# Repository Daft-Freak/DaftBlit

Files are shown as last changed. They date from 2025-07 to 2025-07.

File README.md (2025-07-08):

# DaftBlit
It's... a handheld console?

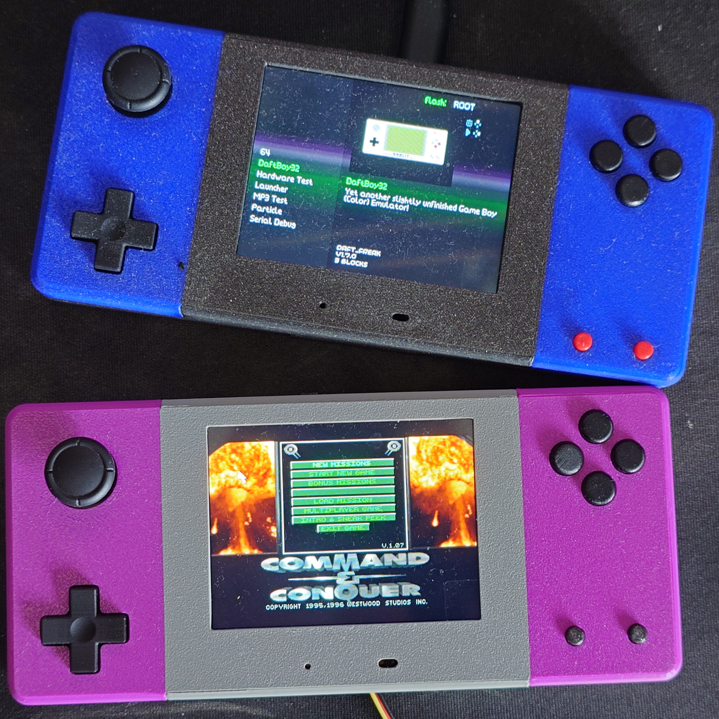
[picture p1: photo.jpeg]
photo of console


## Boards
- [Gamepads](https://github.com/Daft-Freak/py32-i2c-gamepad) (x2)
- `board/extra-buttons`: "Start/Select" buttons
- `board/display`: "Display" / main baard (has some sound/backlight issues)

## 3D Printed Parts
- `abxy.stl` A/B/X/Y buttons (x4)
- `console28-back.stl` back half of case
- `console28-front.stl` front half of case, should be printed face down
- `console28-dbg-cover` cover for debug port access
- `controller-mod-back.stl`/`controller-mod-front.stl` modifiers for multi-colour printing
- `dpad.stl` dpad, requires supports and a bit tricky to print
- `on-off-flat.stl` power button
- `start-select.stl` start/select buttons, requires supports and is very small (x2)

## Other hardware
- Button pads: 2x the dpad part from a GBA SP set.
- LCD: https://www.aliexpress.com/item/1005009128815676.html (2.8 inch 40 pin 240x320 ST7789)
- Speaker: TODO (can't remember if it's https://shop.pimoroni.com/products/mini-speaker-8-1w or not)
- Battery: TODO
- Screws: [TODO](assembly/00-screws2.jpeg) (there are four different ones)
- Cables: 1-2 "short" (50mm?) i2c cables and a longer one (100mm?), 5-pin 0.5mm ffc for start/select buttons
- Joystick: the switch joy-con one
- Brains: RP2350 stamp, the XL one if you want the power button to work
- Optional sensor stick for... sensors

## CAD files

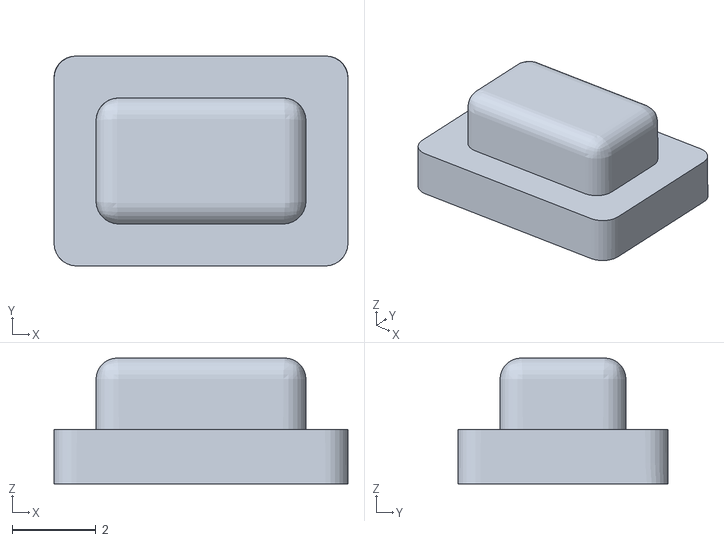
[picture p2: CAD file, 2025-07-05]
3d-print/on-off-flat.stl
7.00 x 5.00 x 3.00

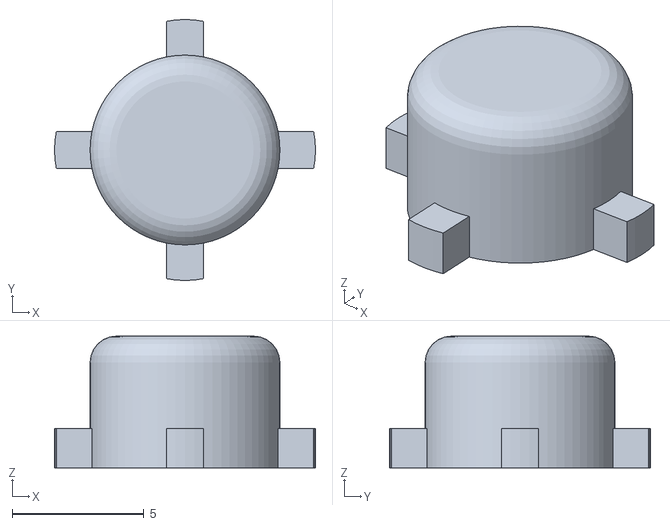
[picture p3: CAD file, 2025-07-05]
3d-print/abxy.stl
9.90 x 9.90 x 5.00

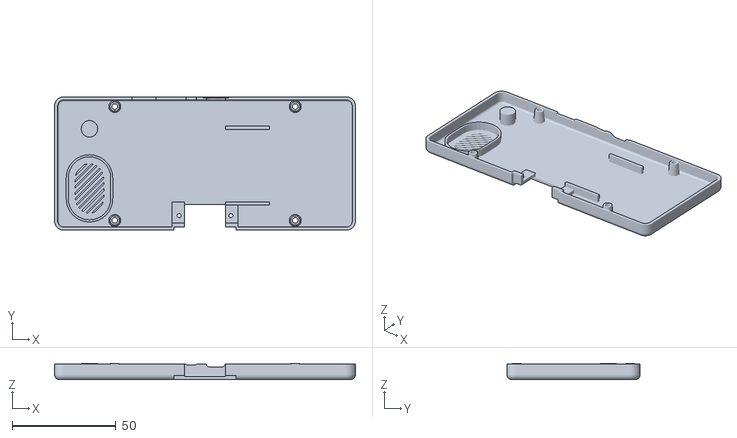
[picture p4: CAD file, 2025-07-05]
3d-print/console28-back.stl
145.4 x 64.4 x 7.85

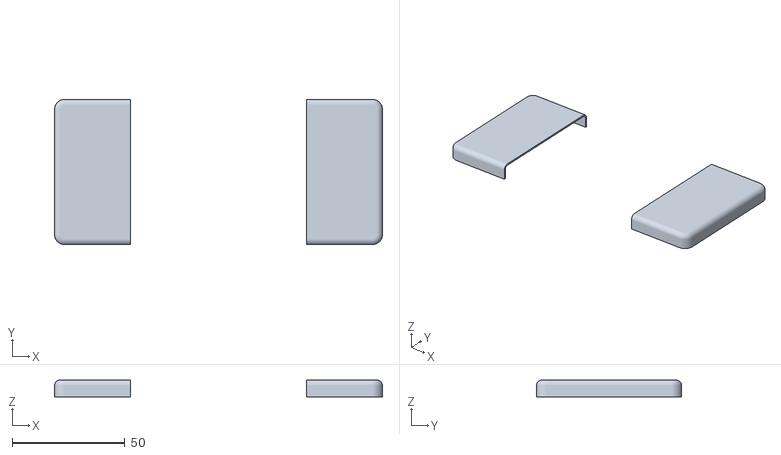
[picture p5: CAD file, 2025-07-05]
3d-print/controller-mod-front.stl
145.4 x 64.4 x 7.50

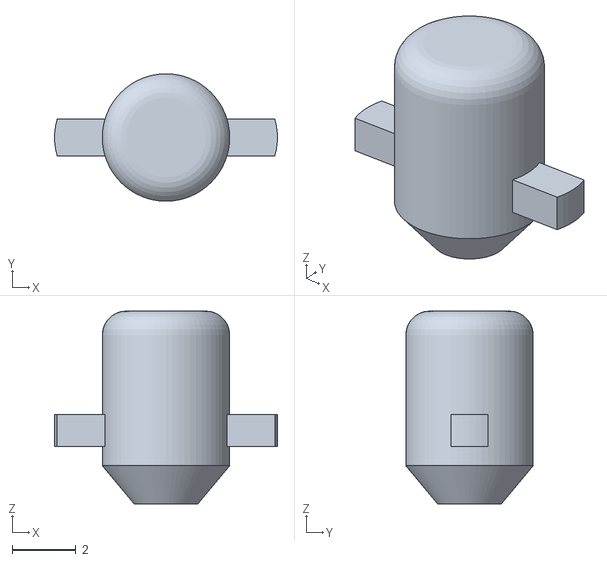
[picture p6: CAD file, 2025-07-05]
3d-print/start-select.stl
7.00 x 4.00 x 6.06

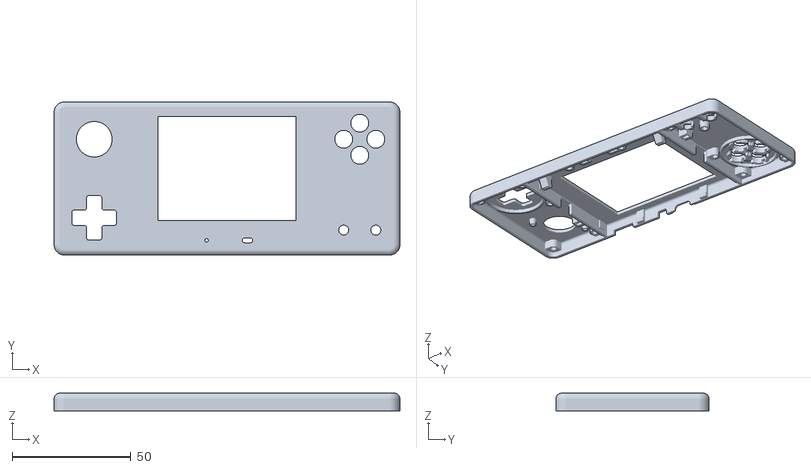
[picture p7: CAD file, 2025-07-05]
3d-print/console28-front.stl
145.4 x 64.4 x 7.50

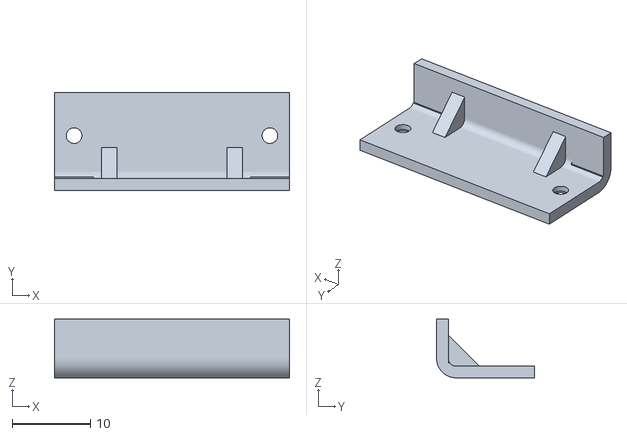
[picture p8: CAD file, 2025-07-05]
3d-print/console28-dbg-cover.stl
30.0 x 12.5 x 7.50

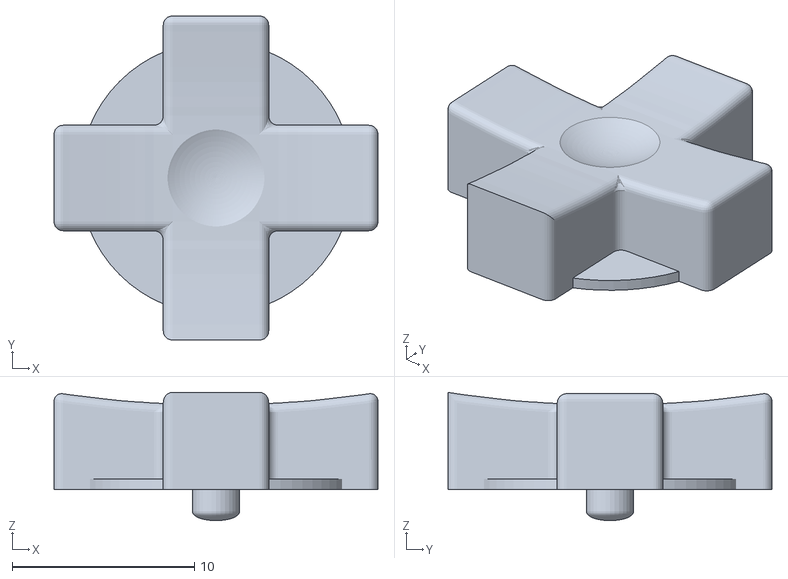
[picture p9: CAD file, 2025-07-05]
3d-print/dpad.stl
17.8 x 17.8 x 7.05

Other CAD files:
3d-print/controller-mod-back.stl

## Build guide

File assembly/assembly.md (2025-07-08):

## Parts
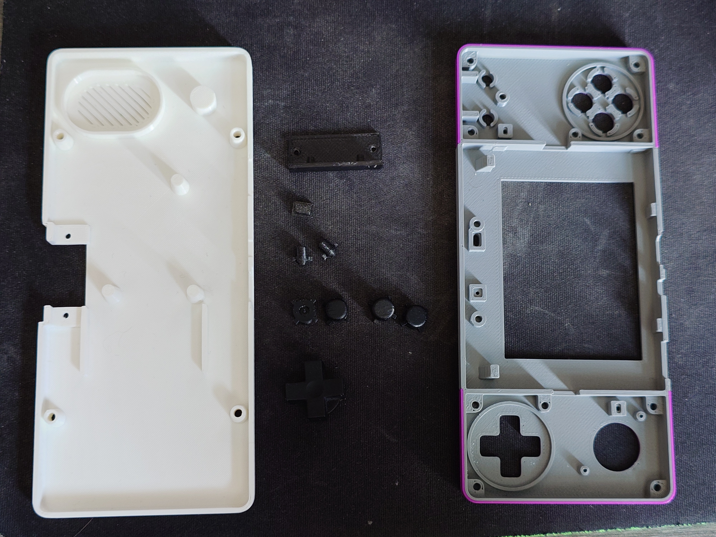
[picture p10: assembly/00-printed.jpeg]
Printed parts

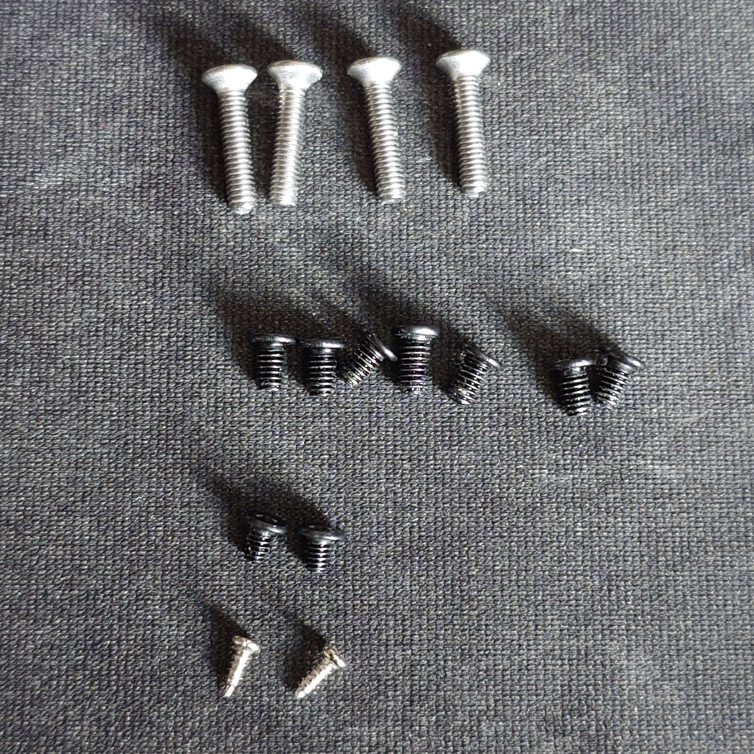
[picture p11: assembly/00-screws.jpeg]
Screws


- 4x M2.5 countersunk
- 5x M2.5 (+2 for sensor stick)
- 2x M2
- 2x ?? for joystick

(TODO: need to measure)

## 1 - Left controller

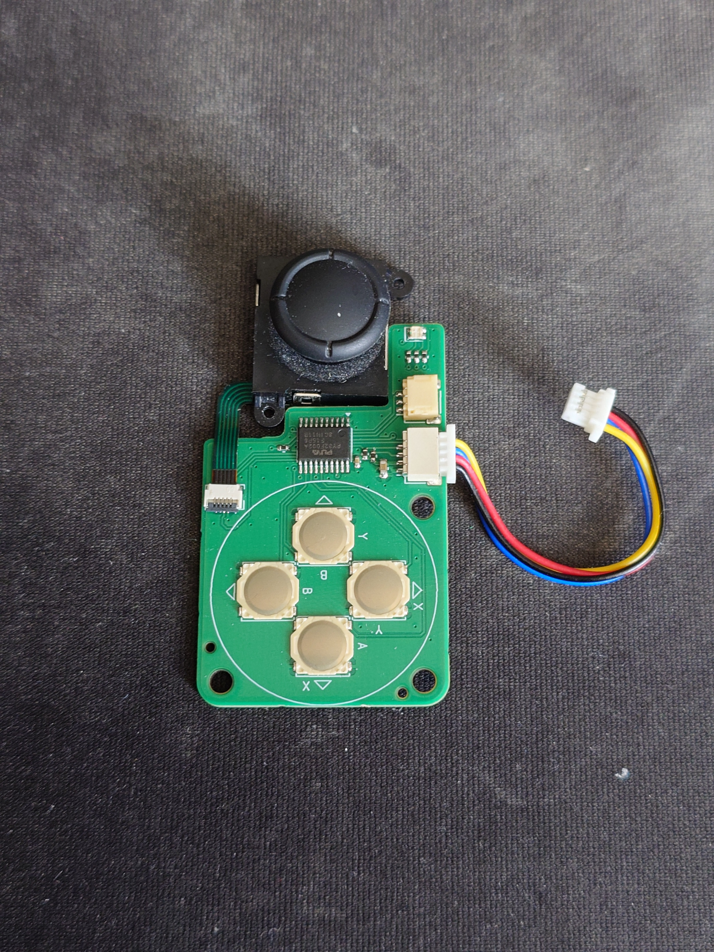
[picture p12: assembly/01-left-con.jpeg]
Left con


## 2 - Right controller

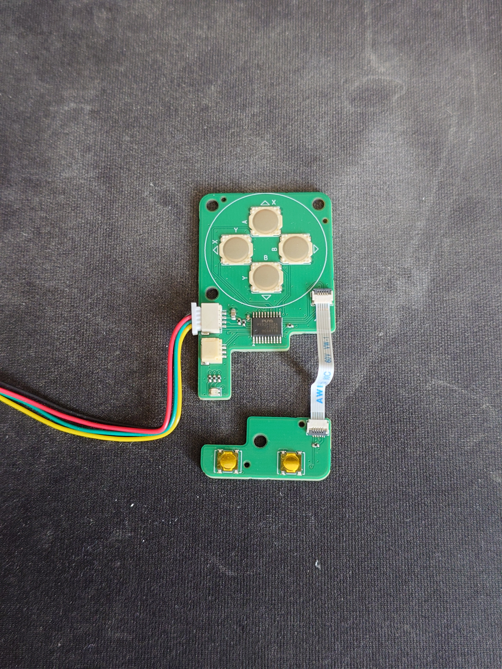
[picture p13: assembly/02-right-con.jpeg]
Right con


## 3 - Display/main board

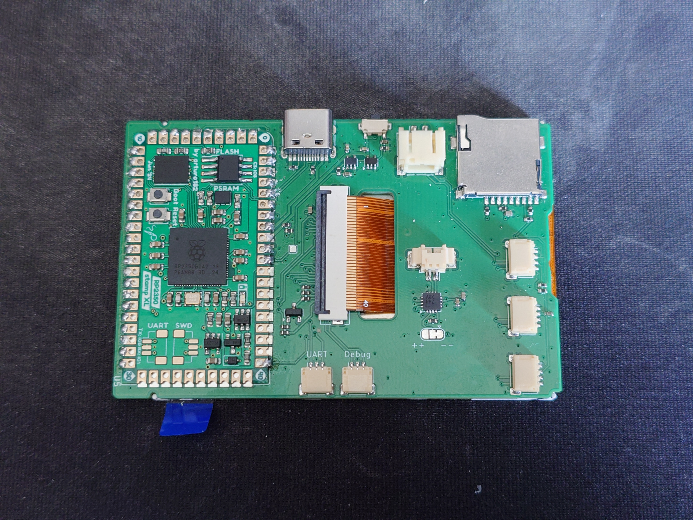
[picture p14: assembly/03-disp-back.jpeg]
Disp back

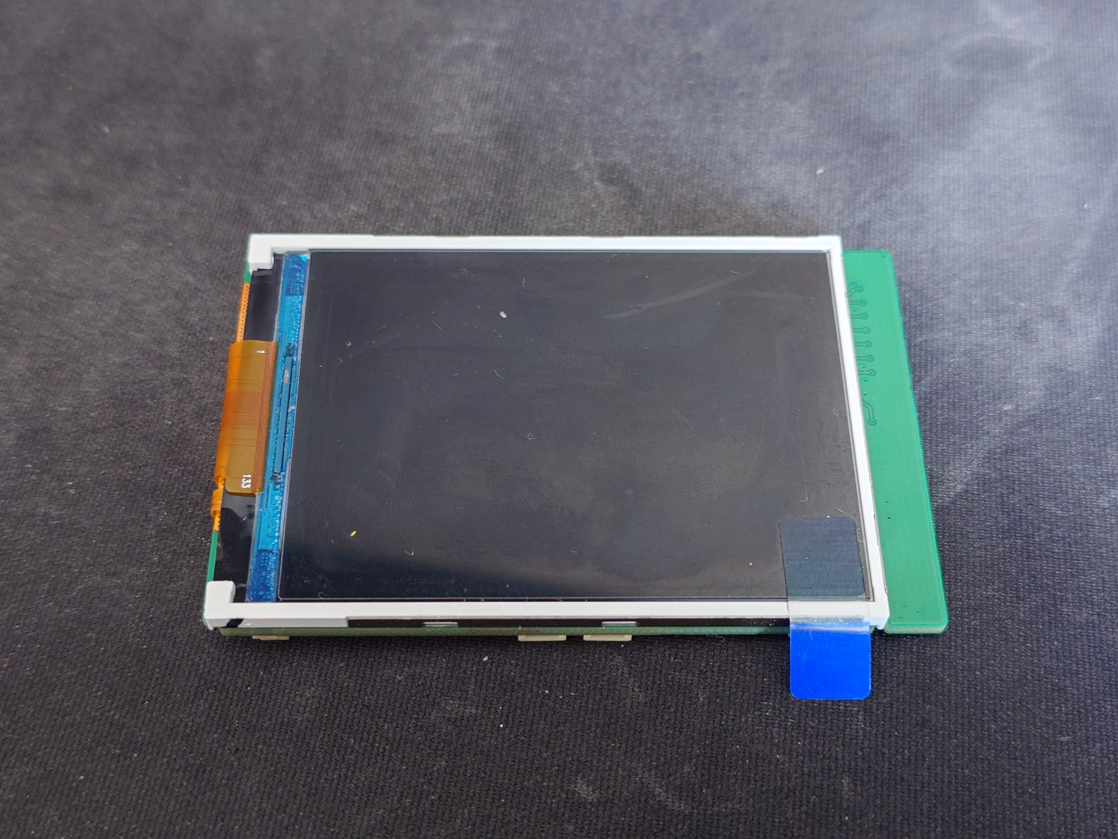
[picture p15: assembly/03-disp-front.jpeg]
Disp front


Stamp soldered, LCD connected and stuck down.

## 4 - Left controls

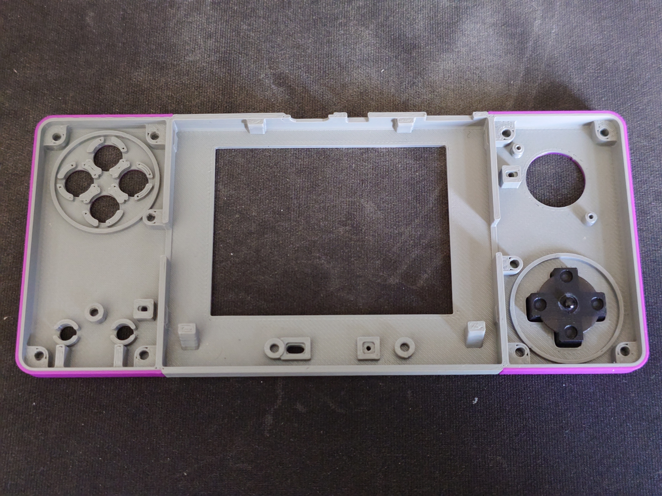
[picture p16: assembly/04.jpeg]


## 5 - 

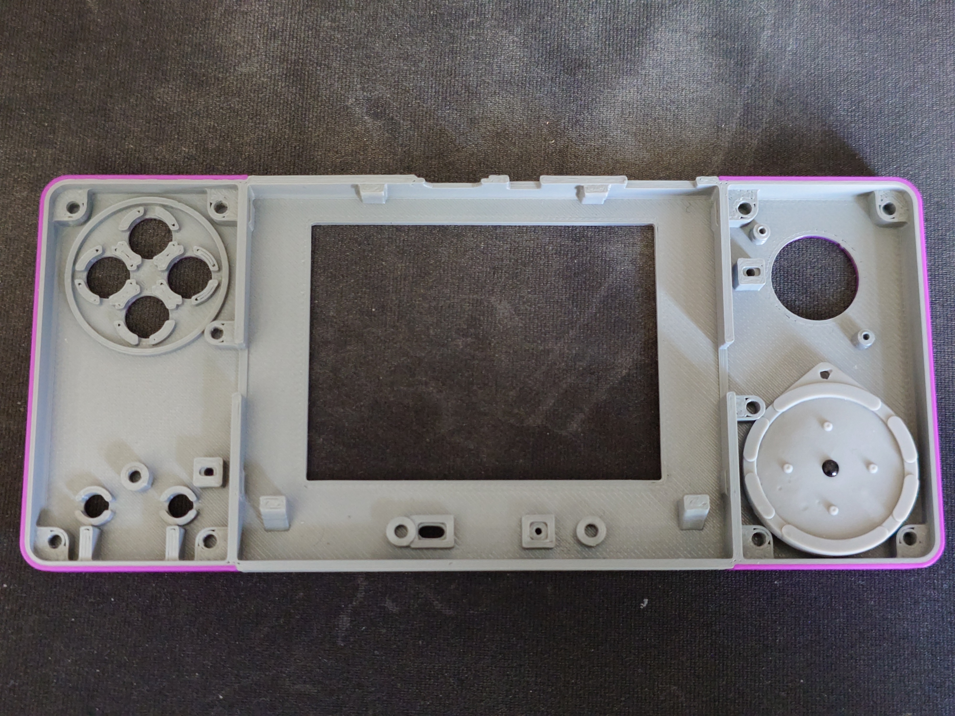
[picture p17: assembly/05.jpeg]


## 6 - 

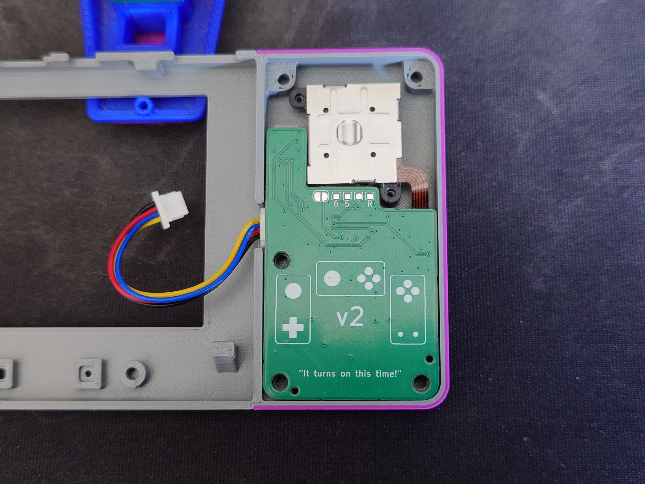
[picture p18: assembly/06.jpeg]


## 7 - 

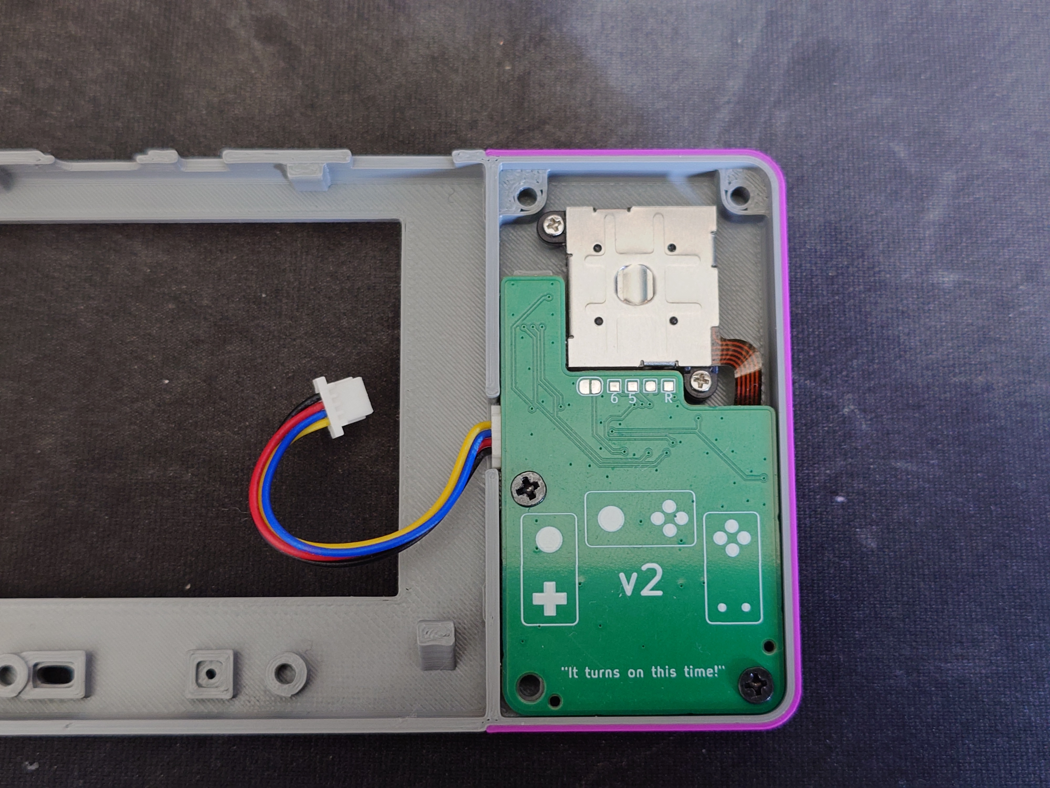
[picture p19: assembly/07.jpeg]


## 8 - Right controls

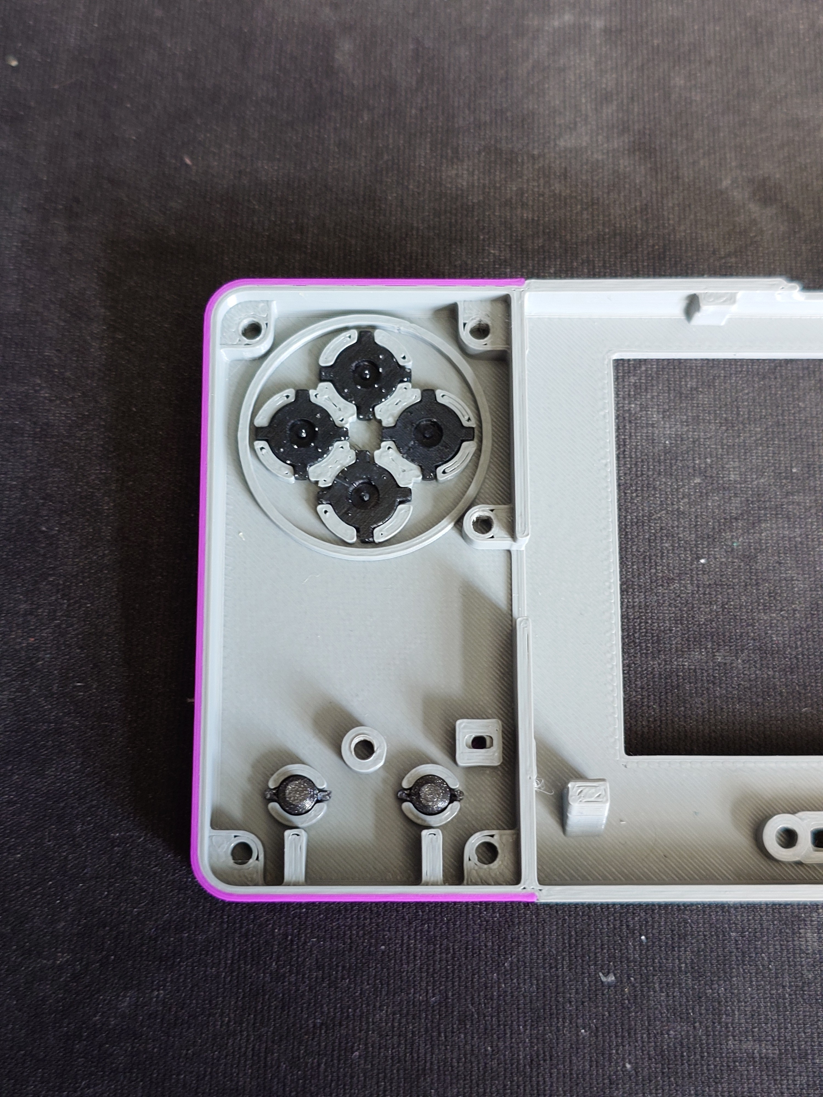
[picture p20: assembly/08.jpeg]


## 9 - 

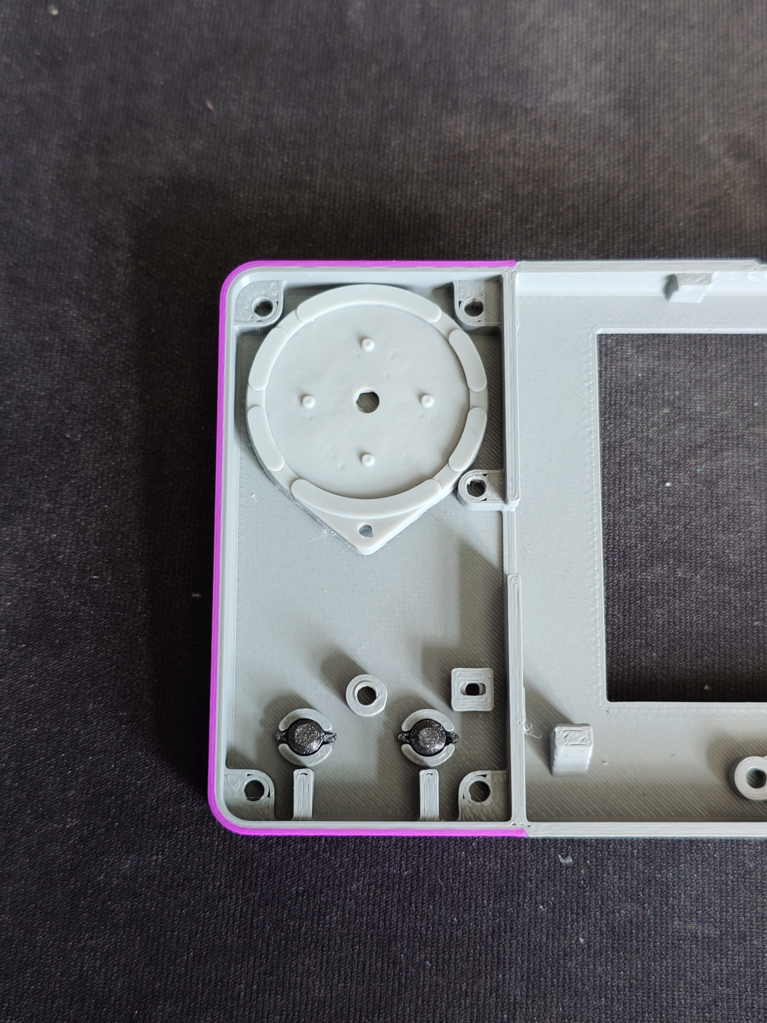
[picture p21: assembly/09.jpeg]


## 10 - 

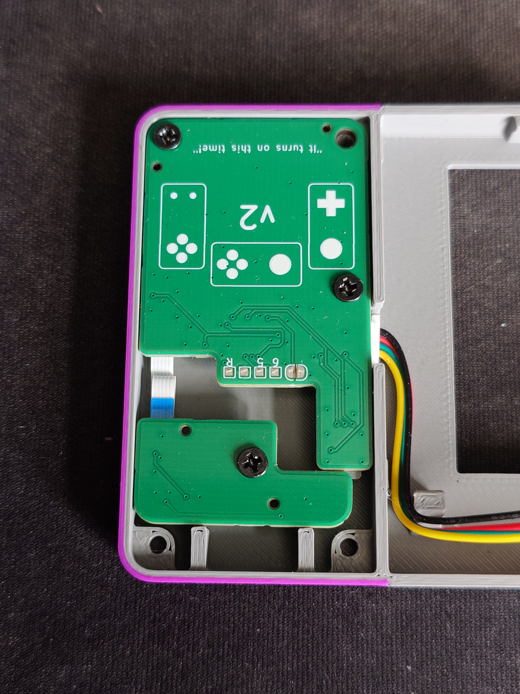
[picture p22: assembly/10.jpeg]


## 11 - Controls done

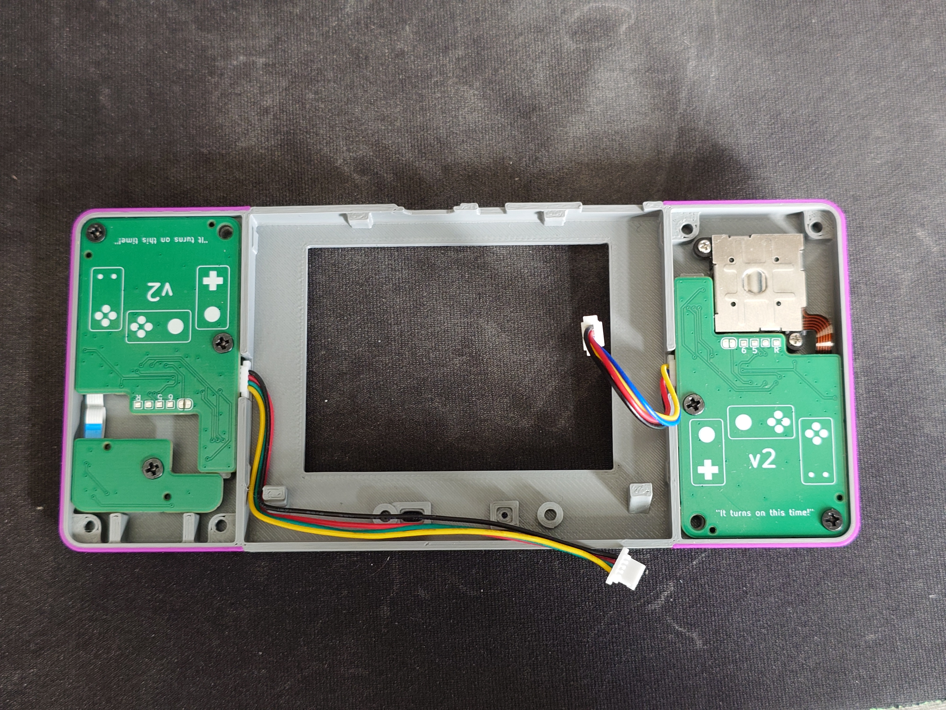
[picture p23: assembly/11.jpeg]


## 12 - Main board

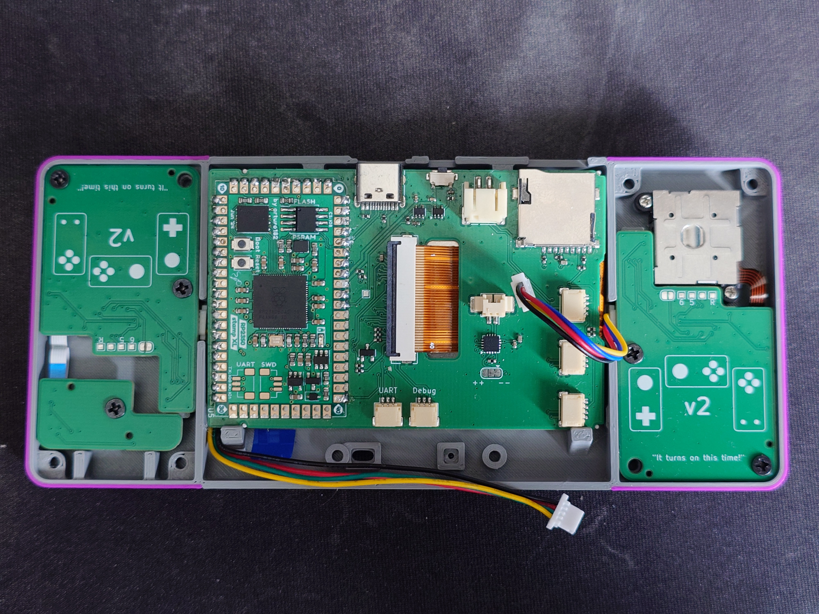
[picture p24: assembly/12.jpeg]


## 13 - 

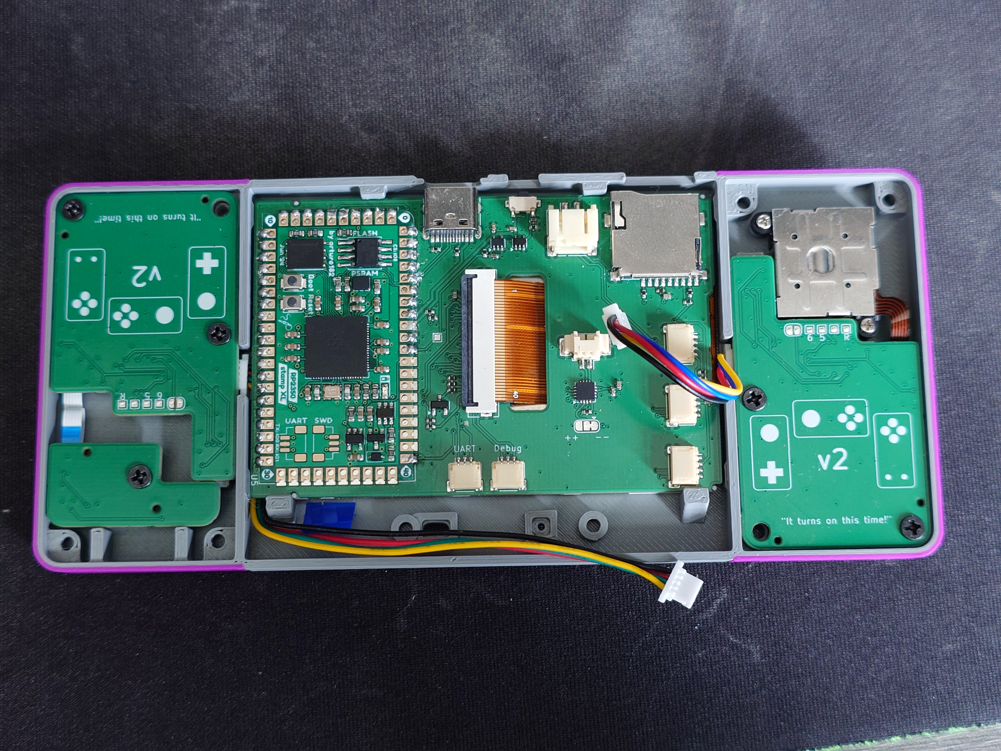
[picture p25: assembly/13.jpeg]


## 14 - 

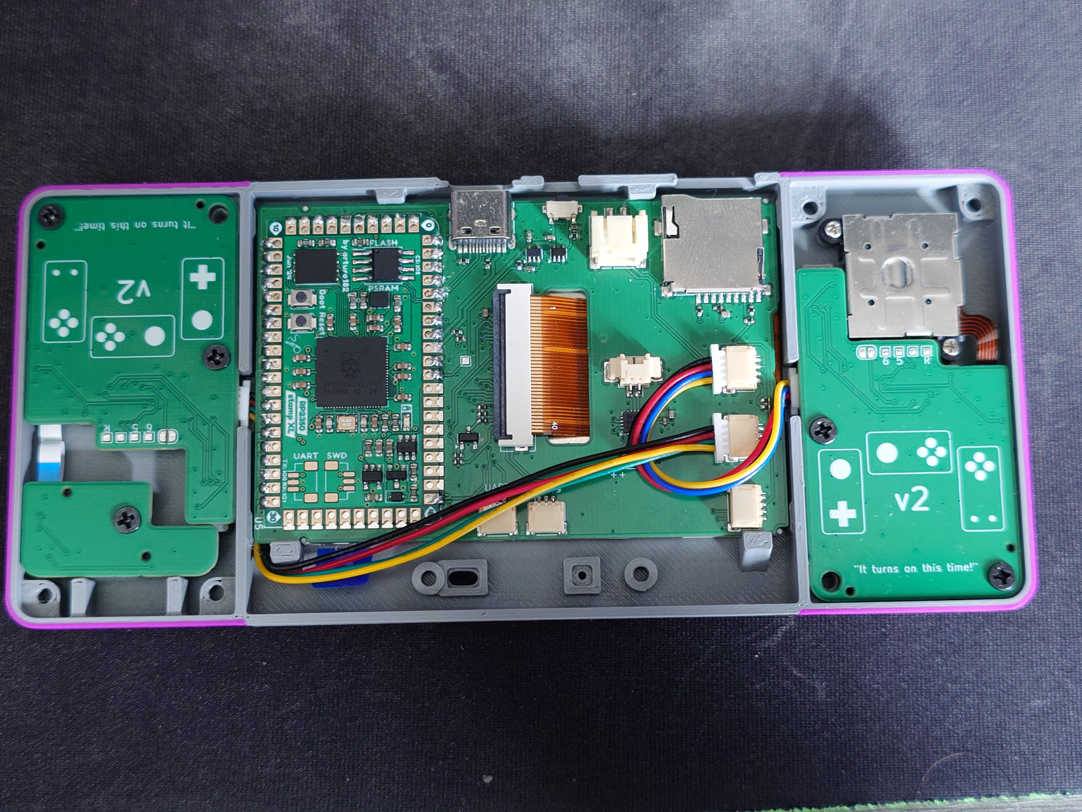
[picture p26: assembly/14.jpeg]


## 15 - Sensor stick (optional)

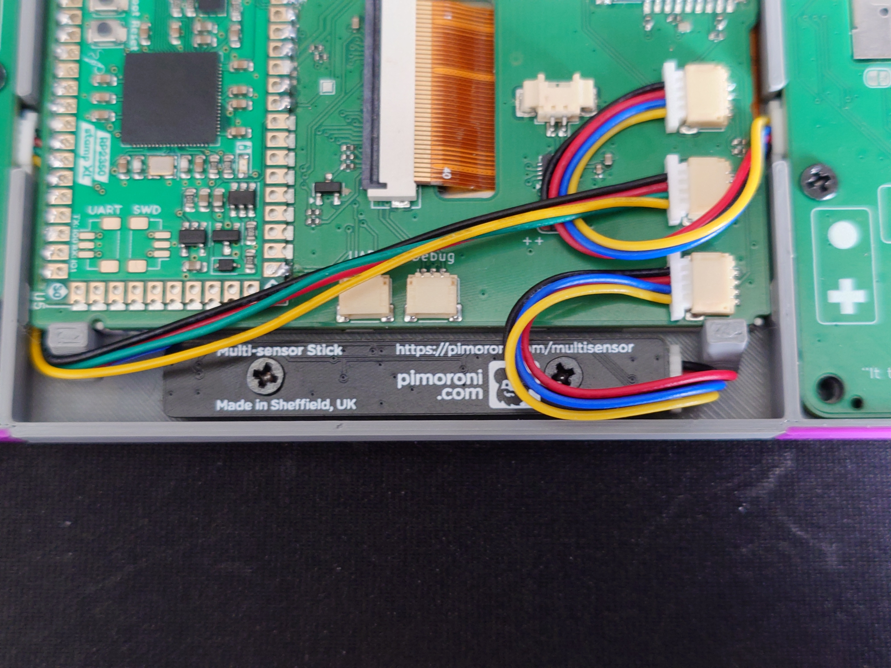
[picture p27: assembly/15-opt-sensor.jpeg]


## ...

- speaker
- battery
- closing case
- debug cover

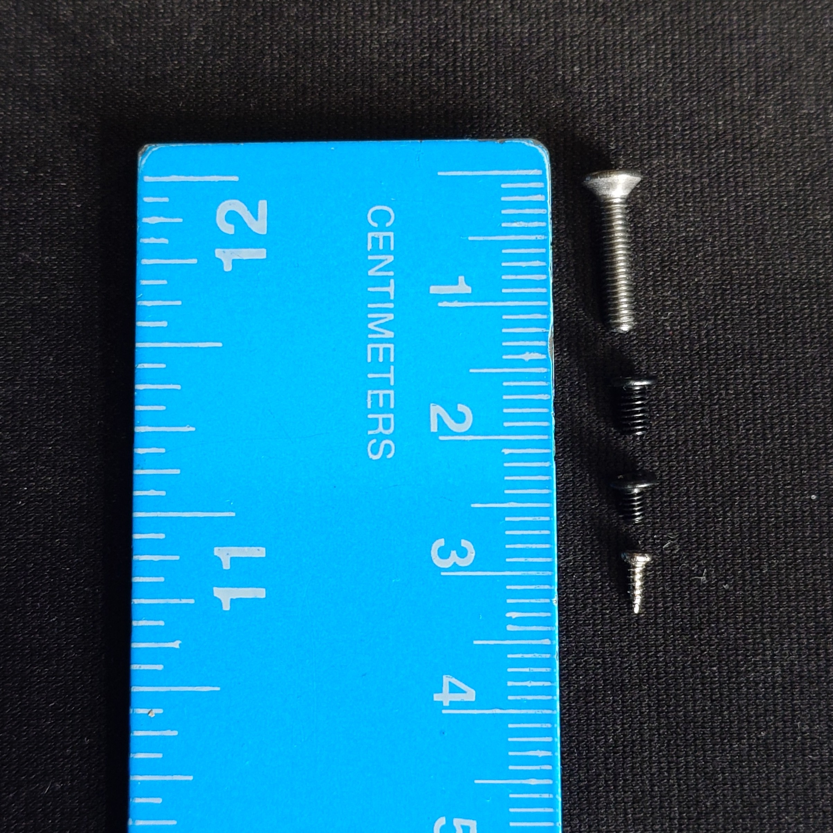
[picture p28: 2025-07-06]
assembly/00-screws2.jpeg

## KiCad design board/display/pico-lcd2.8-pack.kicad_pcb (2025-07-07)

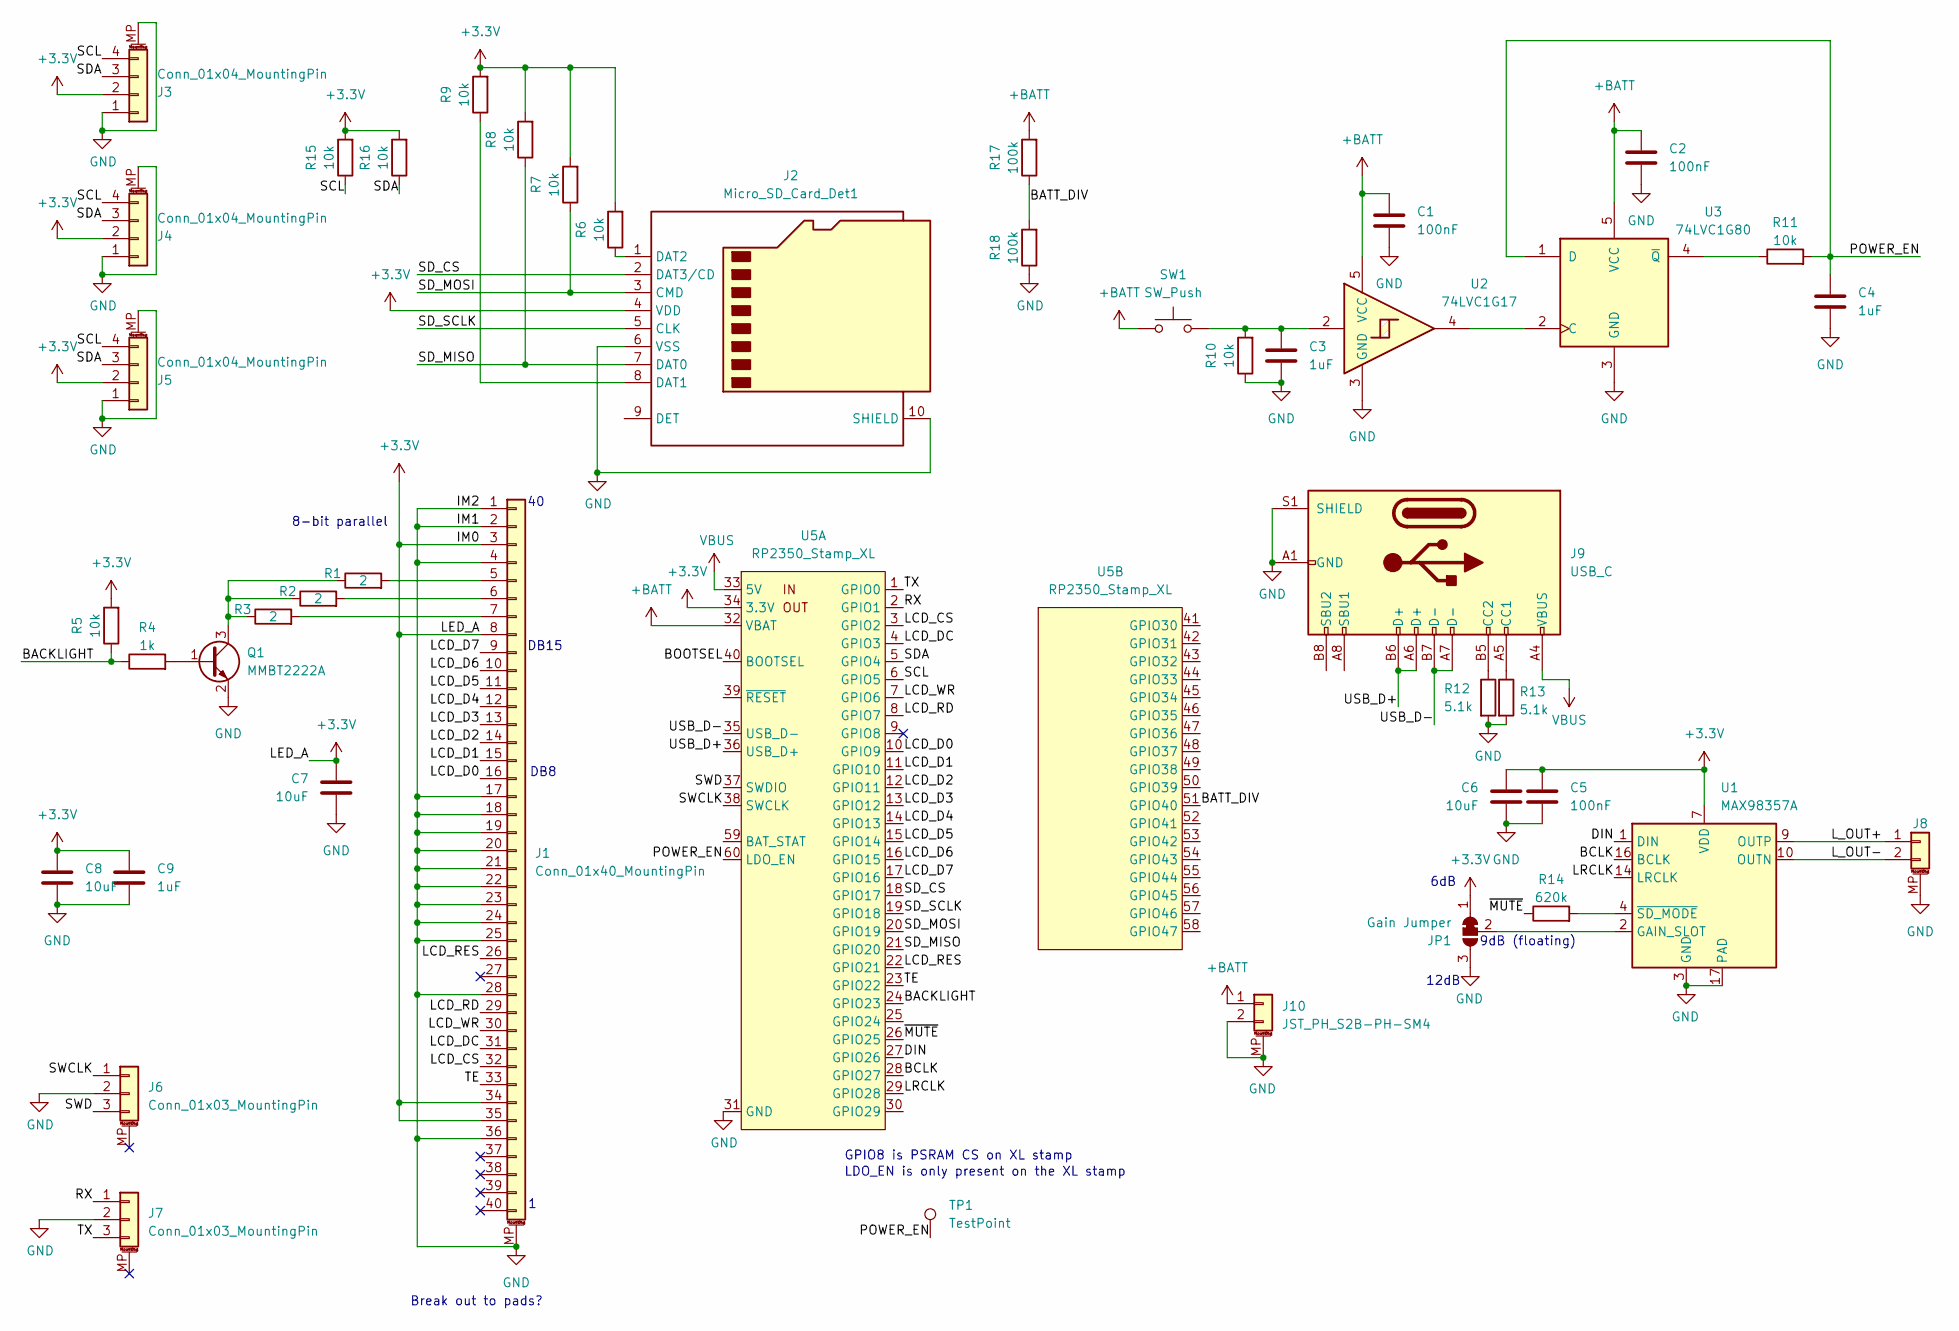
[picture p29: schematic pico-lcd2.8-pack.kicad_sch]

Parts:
C1, C2, C5: 100nF; C_0402_1005Metric
C3, C4, C9: 1uF; C_0402_1005Metric
C6, C7, C8: 10uF; C_0402_1005Metric
J1: Conn_01x40_MountingPin; XUNPU_FPC-05FB-40PH20_1x40-1MP_P0.50mm_Horizontal
J2: Micro_SD_Card_Det1; microSD_HC_Push
J3, J4, J5: Conn_01x04_MountingPin; JST_SH_SM04B-SRSS-TB_1x04-1MP_P1.00mm_Horizontal
J6, J7: Conn_01x03_MountingPin; JST_SH_SM03B-SRSS-TB_1x03-1MP_P1.00mm_Horizontal
J8: 1X02PICOBLADE; Molex_PicoBlade_53261-0271_1x02-1MP_P1.25mm_Horizontal
J9: USB_C; USB_C_Receptacle_HRO_TYPE-C-31-M-12
J10: JST_PH_S2B-PH-SM4; JST_PH_S2B-PH-SM4-TB_1x02-1MP_P2.00mm_Horizontal
JP1: Gain Jumper; SolderJumper-3_P1.3mm_Bridged12_RoundedPad1.0x1.5mm
Q1: MMBT2222A; SOT-23
R1, R2, R3: 2; R_0402_1005Metric
R4: 1k; R_0402_1005Metric
R5, R6, R7, R8, R9, R10, R11, R15, R16: 10k; R_0402_1005Metric
R12, R13: 5.1k; R_0402_1005Metric
R14: 620k; R_0402_1005Metric
R17, R18: 100k; R_0402_1005Metric
SW1: SW_Push; SW_Push_TSA002
TP1: TestPoint; TestPoint_Pad_1.0x1.0mm
U1: MAX98357A; TQFN-16-1EP_3x3mm_P0.5mm_EP1.23x1.23mm
U2: 74LVC1G17; SOT-353_SC-70-5
U3: 74LVC1G80; SOT-353_SC-70-5
U5: RP2350_Stamp_XL; RP2xxx_Stamp_Combo_SMD

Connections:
+3.3V: C5.1, C6.1, C7.1, C8.1, C9.1, J1.3, J1.8, J1.34, J1.35, J2.4 (VDD), J3.2, J4.2, J5.2, JP1.1 (A), R5.2, R6.2, R7.2, R8.2, R9.2, R15.2, R16.2, U1.7 (VDD), U1.8 (VDD), U5.34 (3.3V)
+BATT: C1.1, C2.1, J10.1, R17.2, SW1.1, U2.5 (VCC), U3.5 (VCC), U5.32 (VBAT)
/BACKLIGHT: R4.1, R5.1, U5.24 (GPIO23)
/BATT_DIV: R17.1, R18.2, U5.51 (GPIO40)
/BCLK: U1.16 (BCLK), U5.28 (GPIO27)
/BOOTSEL: U5.40 (BOOTSEL)
/DIN: U1.1 (DIN), U5.27 (GPIO26)
/LCD_CS: J1.32, U5.3 (GPIO2)
/LCD_D0: J1.16, U5.10 (GPIO9)
/LCD_D1: J1.15, U5.11 (GPIO10)
/LCD_D2: J1.14, U5.12 (GPIO11)
/LCD_D3: J1.13, U5.13 (GPIO12)
/LCD_D4: J1.12, U5.14 (GPIO13)
/LCD_D5: J1.11, U5.15 (GPIO14)
/LCD_D6: J1.10, U5.16 (GPIO15)
/LCD_D7: J1.9, U5.17 (GPIO16)
/LCD_DC: J1.31, U5.4 (GPIO3)
/LCD_RD: J1.29, U5.8 (GPIO7)
/LCD_RES: J1.26, U5.22 (GPIO21)
/LCD_WR: J1.30, U5.7 (GPIO6)
/LRCLK: U1.14 (LRCLK), U5.29 (GPIO28)
/L_OUT+: J8.1, U1.9 (OUTP)
/L_OUT-: J8.2, U1.10 (OUTN)
/POWER_EN: C4.1, R11.2, TP1.1, U3.1 (D), U5.60 (LDO_EN)
/RX: J7.1, U5.2 (GPIO1)
/SCL: J3.4, J4.4, J5.4, R15.1, U5.6 (GPIO5)
/SDA: J3.3, J4.3, J5.3, R16.1, U5.5 (GPIO4)
/SD_CS: J2.2 (DAT3/CD), U5.18 (GPIO17)
/SD_MISO: J2.7 (DAT0), R8.1, U5.21 (GPIO20)
/SD_MOSI: J2.3 (CMD), R7.1, U5.20 (GPIO19)
/SD_SCLK: J2.5 (CLK), U5.19 (GPIO18)
/SWCLK: J6.1, U5.38 (SWCLK)
/SWD: J6.3, U5.37 (SWDIO)
/TE: J1.33, U5.23 (GPIO22)
/TX: J7.3, U5.1 (GPIO0)
/USB_D+: J9.A6 (D+), J9.B6 (D+), U5.36 (USB_D+)
/USB_D-: J9.A7 (D-), J9.B7 (D-), U5.35 (USB_D-)
/~MUTE: R14.1, U5.26 (GPIO25)
GND: C1.2, C2.2, C3.2, C4.2, C5.2, C6.2, C7.2, C8.2, C9.2, J1.1, J1.2, J1.4, J1.17, J1.18, J1.19, J1.20, J1.21, J1.22, J1.23, J1.24, J1.25, J1.28, J1.36, J1.MP (MountPin), J2.6 (VSS), J2.10 (SHIELD), J3.1, J3.MP (MountPin), J4.1, J4.MP (MountPin), J5.1, J5.MP (MountPin), J6.2, J7.2, J8.MP (MountPin), J9.A1 (GND), J9.A12 (GND), J9.B1 (GND), J9.B12 (GND), J9.S1 (SHIELD), J10.2, J10.MP (MountPin), JP1.3 (B), Q1.2 (E), R10.1, R12.2, R13.2, R18.1, U1.3 (GND), U1.11 (GND), U1.15 (GND), U1.17 (PAD), U2.3 (GND), U3.3 (GND), U5.31 (GND)
unnamed: C3.1, R10.2, SW1.2, U2.2
unnamed: J1.5, R1.2
unnamed: J1.6, R2.2
unnamed: J1.7, R3.2
unnamed: J2.8 (DAT1), R9.1
unnamed: J2.1 (DAT2), R6.1
unnamed: J9.A5 (CC1), R13.1
unnamed: J9.B5 (CC2), R12.1
unnamed: JP1.2 (C), U1.2 (GAIN_SLOT)
unnamed: Q1.1 (B), R4.2
unnamed: Q1.3 (C), R1.1, R2.1, R3.1
unnamed: R14.2, U1.4 (~SD_MODE)
unnamed: U2.4, U3.2 (C)
unnamed: R11.1, U3.4 (~Q)
VBUS: J9.A4 (VBUS), J9.A9 (VBUS), J9.B4 (VBUS), J9.B9 (VBUS), U5.33 (5V)

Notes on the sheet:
LDO_EN is only present on the XL stamp
6dB
GPIO8 is PSRAM CS on XL stamp
8-bit parallel
Break out to pads?
12dB
9dB (floating)
DB15
DB8

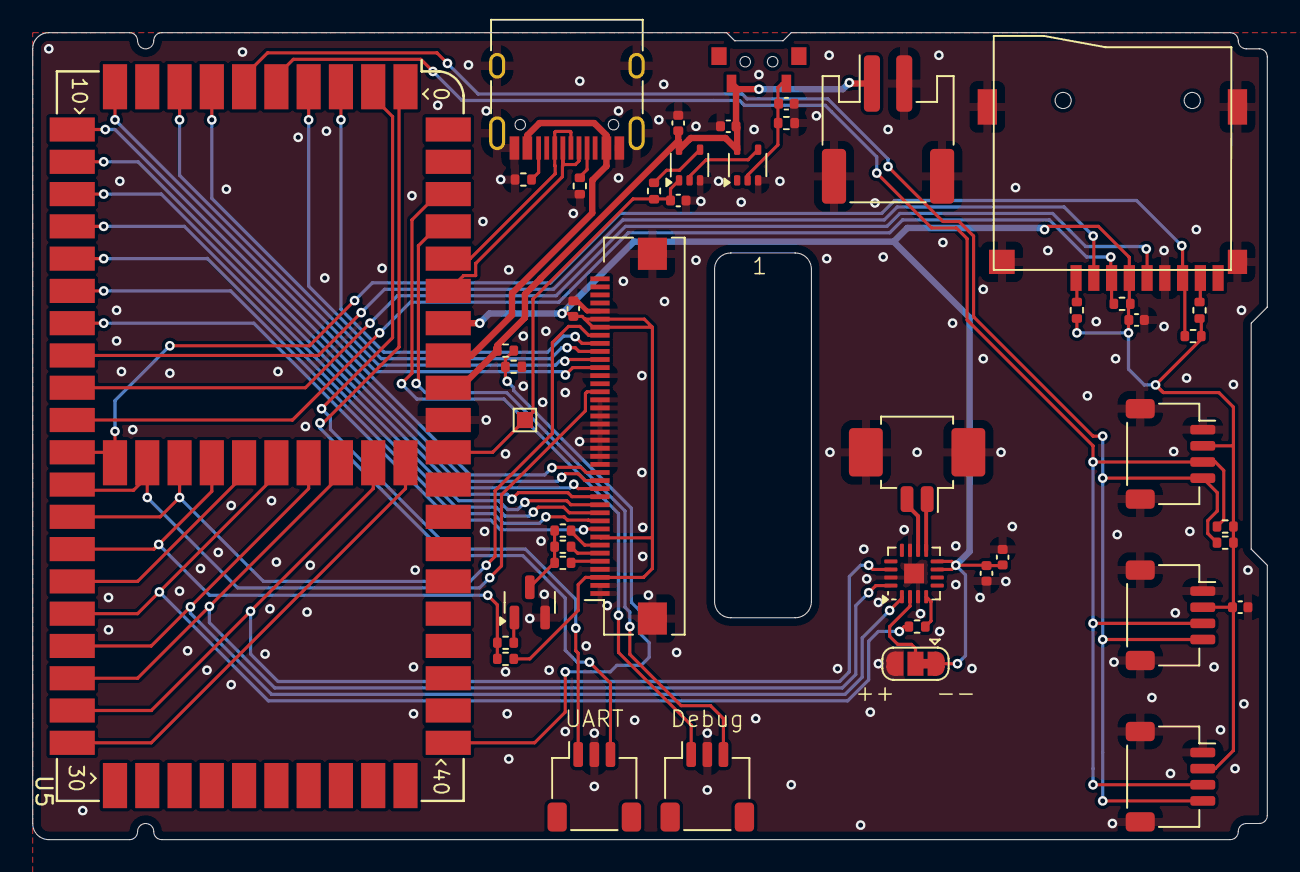
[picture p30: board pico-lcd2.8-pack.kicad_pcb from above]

Board: 2 copper layers, 76.5 x 50.0 mm, 45 parts (0 on the bottom side), 53 nets.

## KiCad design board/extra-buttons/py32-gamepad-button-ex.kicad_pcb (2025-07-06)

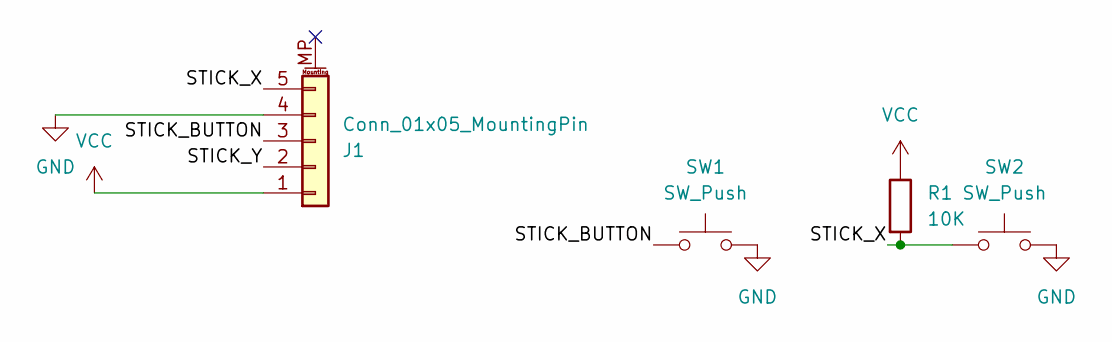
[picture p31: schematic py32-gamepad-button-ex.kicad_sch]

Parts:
J1: Conn_01x05_MountingPin; HCTL_HC-FPC-05-09-5RLTAG-00_1x05-1MP_P0.50mm_Horizontal
R1: 10K; R_0402_1005Metric
SW1, SW2: SW_Push; SW_Push_1P1T_NO_TSC001

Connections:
/STICK_BUTTON: J1.3, SW1.1
/STICK_X: J1.5, R1.2, SW2.1
/STICK_Y: J1.2
GND: J1.4, SW1.2, SW2.2
VCC: J1.1, R1.1

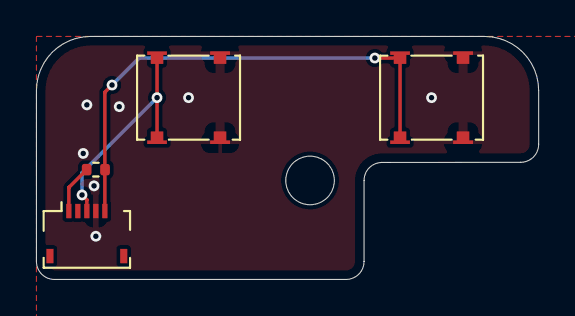
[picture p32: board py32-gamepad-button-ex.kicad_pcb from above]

Board: 2 copper layers, 27.9 x 13.5 mm, 4 parts (0 on the bottom side), 4 nets.

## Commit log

2025-07-05 Add 3d-printed parts
    [abxy.stl, console28-back.stl, console28-dbg-cover.stl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]
2025-07-06 Photos of assembled boards
2025-07-06 Some assembly
2025-07-06 Add "extra buttons" board
    This one is straightforward...
    [py32-gamepad-button-ex.kicad_pcb, py32-gamepad-button-ex.kicad_sch]
2025-07-07 Extra buttons are there now
2025-07-07 Add the "display" board
    I think this is the current version, sound/backlight issues included...
    [pico-lcd2.8-pack.kicad_pcb, pico-lcd2.8-pack.kicad_sch]
2025-07-08 Start assembling the assembly photos
